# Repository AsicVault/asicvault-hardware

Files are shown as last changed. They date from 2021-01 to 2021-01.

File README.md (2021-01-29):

# Hardware design of AsicVault

https://asicvault.io/

## Schematics (Altium and PDF versions)

Schematics files of AsicVault hardware wallet rev2.0.6 are located at [**electronics**](https://github.com/AsicVault/asicvault-hardware/tree/main/electronics) folder.

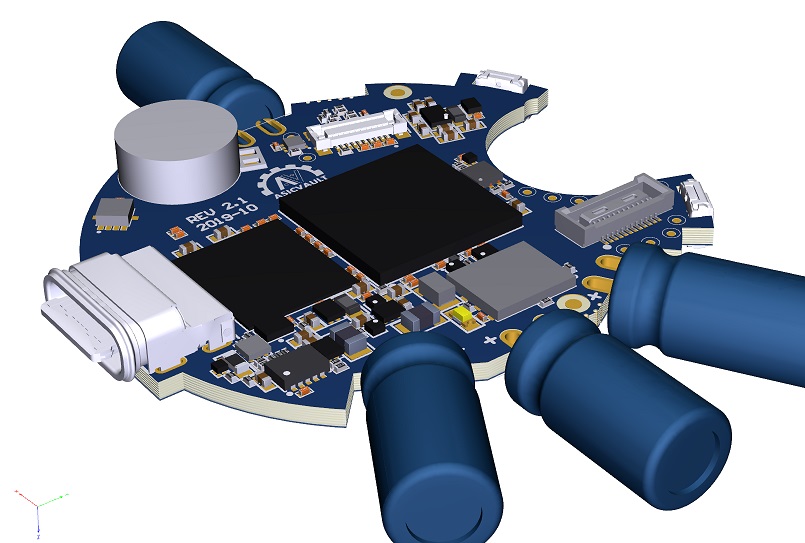
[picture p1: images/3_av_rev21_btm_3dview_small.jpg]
AsicVault PCB 3D bottom view


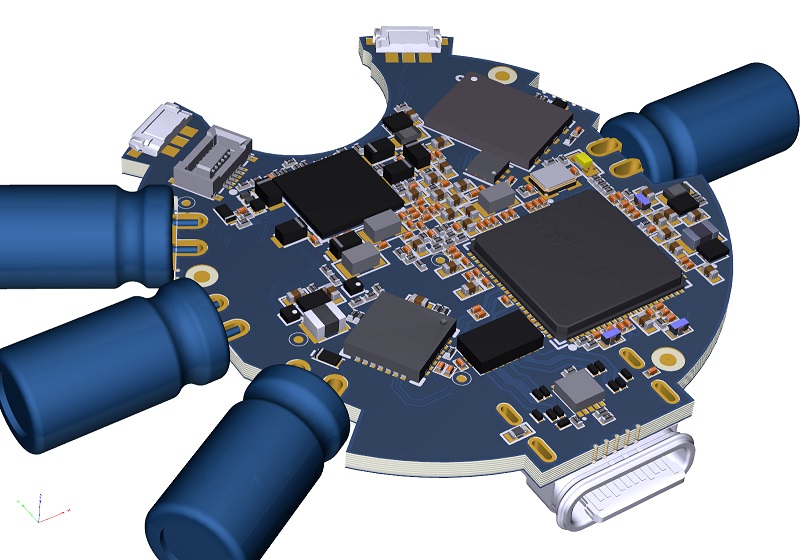
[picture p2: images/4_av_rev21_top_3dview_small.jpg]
AsicVault PCB 3D top view


## Development Kit

Development kit carrier board schematics and PCB design files are located at [**devkit**](https://github.com/AsicVault/asicvault-hardware/tree/main/devkit) folder.

## License

AsicVault Hardware is distributed under [**Solderpad Hardware License v2.1 with Commons Clause**](https://github.com/AsicVault/asicvault-hardware/blob/main/LICENSE.md) license.

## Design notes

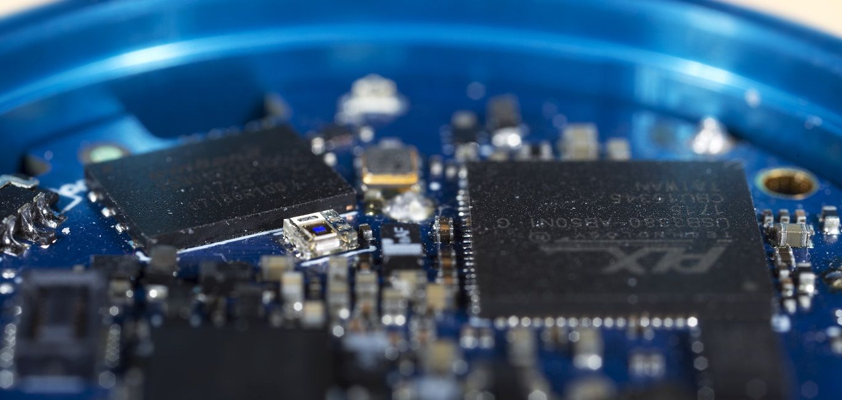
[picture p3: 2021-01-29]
photos/IMG_0519_s25.jpg

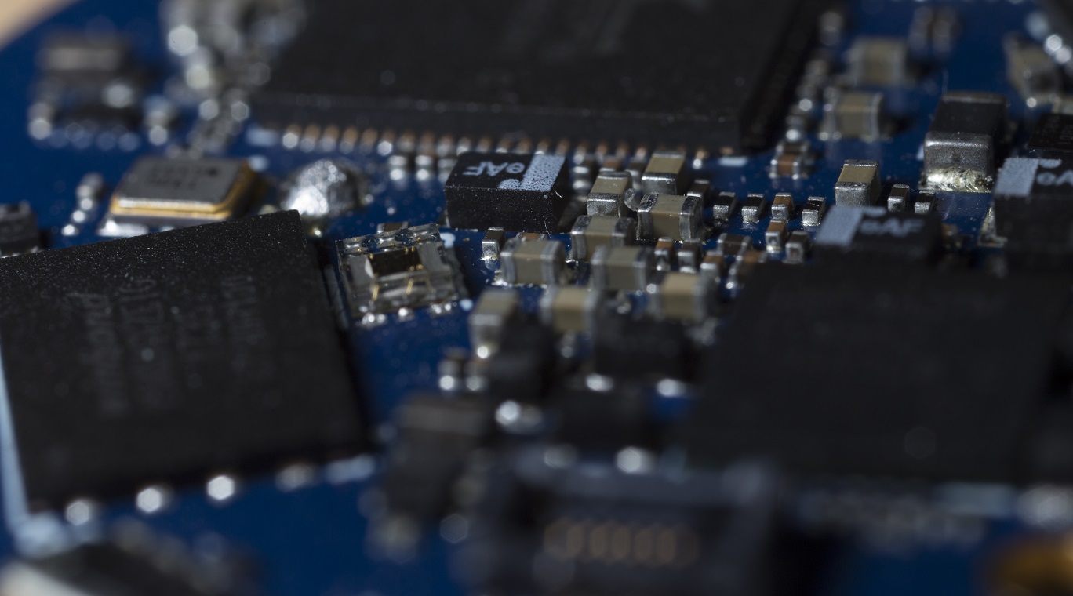
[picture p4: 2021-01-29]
photos/IMG_0346_s25.jpg

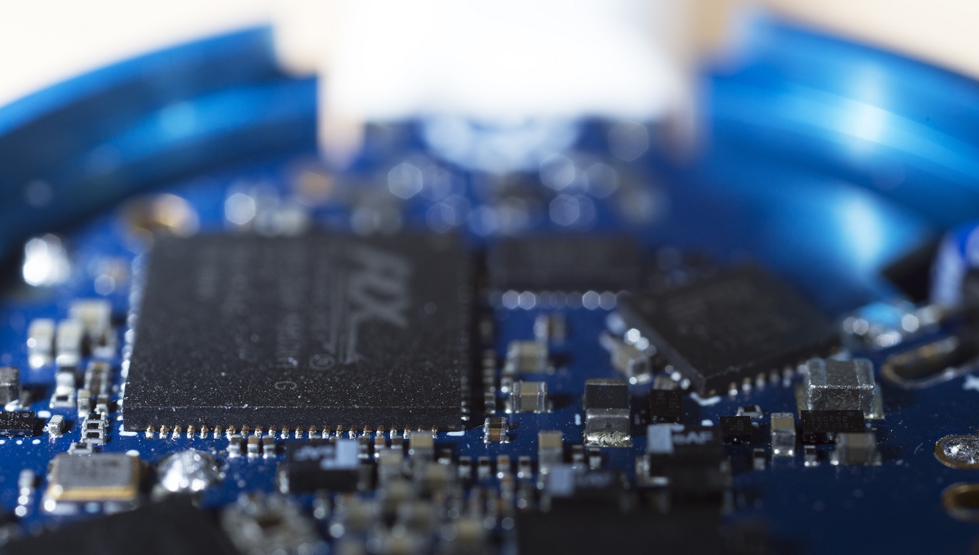
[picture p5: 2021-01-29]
photos/IMG_0522_s25.jpg

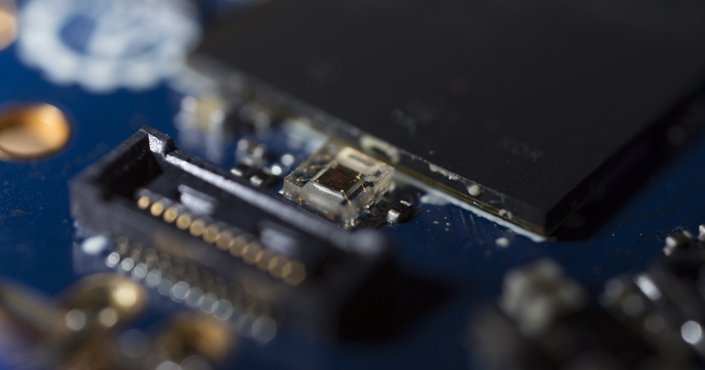
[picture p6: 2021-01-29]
photos/IMG_0318_s25.jpg

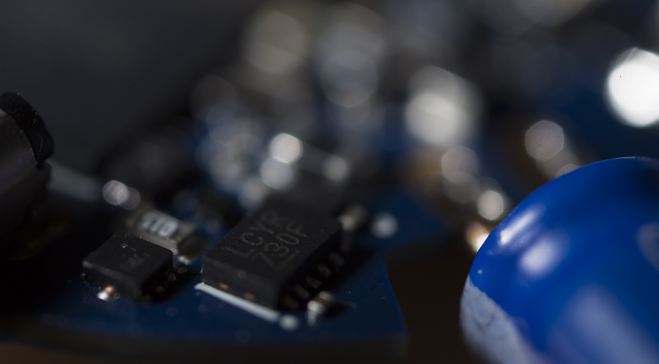
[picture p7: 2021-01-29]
photos/IMG_0329_s25.jpg

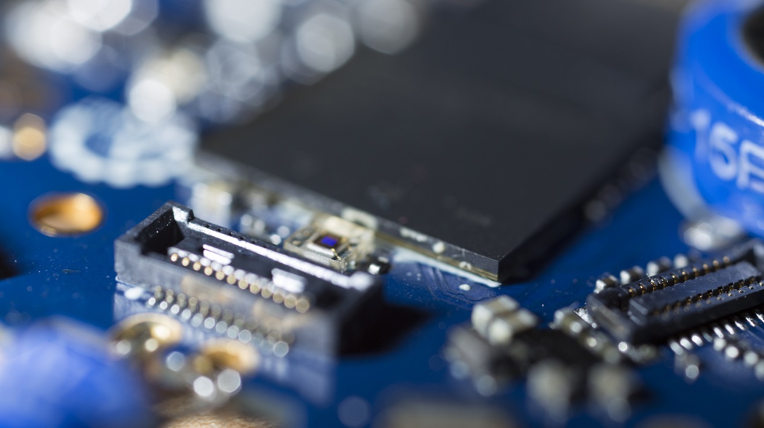
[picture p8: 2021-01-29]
photos/IMG_0317_s25.jpg

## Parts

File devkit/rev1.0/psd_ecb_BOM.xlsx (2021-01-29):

Bill of Material for | PSD_ECB
On 12/12/2017 at 14:17:52 |  |  | Tellimus | 5
Comment | Pattern | Quantity | Components |  | Tellimuse kogus | Order code | Replacement 1
0R | R0603 | 39 | R2, R3, R4, R5, R6, R7, R8, R9, R10, R11, R12, R14, R15, R16, R24, R25, R26, R27, R28, R29, R30, R31, R32, R33, R34, R35, R36, R37, R38, R40, R41, R42, R43, R44, R45, R46 |  | 195 | 603-RC0603JR-070RL (https://www.mouser.ee/ProductDetail/Yageo/RC0603JR-070RL/?qs=sGAEpiMZZMu61qfTUdNhG5eFuApKbqVdMPNPP1VDJp4%3d)
750R | R0603 | 3 | R18, R20, R22 |  | 15 | 603-RC0603FR-07750RL (https://www.mouser.ee/ProductDetail/Yageo/RC0603FR-07750RL/?qs=sGAEpiMZZMtlubZbdhIBIPrUdgJV0nB595rhZqGCp0E%3d)
1.2pF | CAPC1005X04L | 2 | C19, C20 | Capacitor, NP0, ±0.1pF | 10 | 81-GRM1555C1H1R2BA1D (https://www.mouser.ee/ProductDetail/Murata-Electronics/GRM1555C1H1R2BA01D/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)
10µH | INDC1608X06L | 1 | L2 | Inductor, 80mA, ±10% | 5 | 963-LBMF1608T100K (https://www.mouser.ee/ProductDetail/Taiyo-Yuden/LBMF1608T100K/)
100nF | 0603C | 14 | C1, C2, C3, C4, C5, C6, C9, C10, C11, C13, C14, C15, C16, C23 |  | 70 | 710-885012206071 (https://www.mouser.ee/ProductDetail/Wurth-Electronics/885012206071/)
10uF | C0805 | 2 | C8, C12 |  | 10 | 77-VJ0805G106KXQTBC (https://www.mouser.ee/ProductDetail/Vishay-Vitramon/VJ0805G106KXQTW1BC/)
15nH | INDC1005X04L | 1 | L1 | Inductor, 320mA, ±5% | 5 | 963-HK100515NJ-T (https://www.mouser.ee/ProductDetail/Taiyo-Yuden/HK100515NJ-T/)
1K | R0603 | 1 | R13 |  | 5 | 603-RC0603FR-071KL (https://www.mouser.ee/ProductDetail/Yageo/RC0603FR-071KL/)
1nF | 0603C | 1 | C7 |  | 5 | 710-885012206059 (https://www.mouser.ee/ProductDetail/Wurth-Electronics/885012206059/)
1uF | 0603C | 3 | C17, C18, C24 |  | 15 | 710-885012106010 (https://www.mouser.ee/ProductDetail/Wurth-Electronics/885012106010/)
300pF | CAPC1608X06L | 6 | C21, C25, C26, C27, C28, C29 | Capacitor, X5R, ±10% | 30 | 603-CC603JRNPO9BN301 (https://www.mouser.ee/ProductDetail/Yageo/CC0603JRNPO9BN301/?qs=sGAEpiMZZMs0AnBnWHyRQCF1lTWZ1EBLaBLolnZHR5s%3d)
32.768kHz | XTAL_3215 | 1 | X1 | EPSON TOYOCOM - FC-135 32.768KHZ ±20PPM,9.0PF - CRYSTAL, SM, WATCH | 5 | 732-FC135-32.76KAAC3 (https://www.mouser.ee/ProductDetail/Epson-Timing/FC-135-327680KA-AC3/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) | 1278037 (http://ee.farnell.com/epson/q13fc13500003-fc-135-32-768khz-9-0pf/crystal-fc-135-32-768-khz-9-pf/dp/1278037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)
4.7K | R0603 | 2 | R1, R39 |  | 10 | 603-RC0603FR-074K7L (https://www.mouser.ee/ProductDetail/Yageo/RC0603FR-074K7L/?qs=sGAEpiMZZMu61qfTUdNhG5eFuApKbqVdTnYbjySMIr8%3d)
4.7uF | 0603C | 1 | C22 |  | 5 | 581-06036D475KAT4A (https://www.mouser.ee/ProductDetail/AVX/06036D475KAT4A/)
430773034825 | 4307x30348xx_6x6x3.4 | 3 | S1, S2, S3 | WS-TASV 6x6mm J-Hook Hermetic Tact Switch, SMD version | 15 | 710-430773034825 (https://www.mouser.ee/ProductDetail/Wurth-Electronics/430773034825/)
47K | R0603 | 1 | R23 |  | 5 | 603-RC0603FR-0747KL (https://www.mouser.ee/ProductDetail/Yageo/RC0603FR-0747KL/?qs=sGAEpiMZZMu61qfTUdNhG5eFuApKbqVdtD8IoZ5tOEg%3d)
61201021621 | 61201021621 | 1 | J5 | WR-BHD 2.54mm Male Box Header | 5 | 710-61201021621 (https://www.mouser.ee/ProductDetail/Wurth-Electronics/61201021621/)
61201421621 | 61201421621 | 1 | J6 | WR-BHD 2.54mm Male Box Header | 5 | 710-61201421621 (https://www.mouser.ee/ProductDetail/Wurth-Electronics/61201421621/)
61300211121 | 61300211121 | 3 | J3, J7, J9 | WR-PHD 2.54 mm THT Pin Header, 2p | 15 | 710-61300211121 (https://www.mouser.ee/ProductDetail/Wurth-Electronics/61300211121/)
61300311121 | 61300311121 | 1 | J4 | WR-PHD 2.54 mm THT Pin Header, 3p | 5 | 710-61300311121 (https://www.mouser.ee/ProductDetail/Wurth-Electronics/61300311121/)
61300911121 | 61300911121 | 1 | J8 | WR-PHD 2.54 mm THT Pin Header, 9p | 5 | 710-61300911121 (https://www.mouser.ee/ProductDetail/Wurth-Electronics/61300911121/)
61301021121 | 61301021121 | 3 | J10, J11, J12 | WR-PHD 2.54 mm THT Dual Pin Header, 10p | 15 | 710-61301021121 (https://www.mouser.ee/ProductDetail/Wurth-Electronics/61301021121/)
62201021121 | 62201021121 | 1 | J13 | WR-PHD 1.27 mm THT Dual Pin Header, 10p | 5 | 10-62201021121 (https://www.mouser.ee/ProductDetail/Wurth-Electronics/62201021121/)
68712014022 | ZIF_0.5MM_20P | 1 | J2 |  | 5 | 710-68712014022 (https://www.mouser.ee/ProductDetail/Wurth-Electronics/68712014022/)
APTD1608LSECK/J4-PF | LED0603 | 3 | LED1, LED2, LED3 |  | 15 | 604-APTD1608LSECKJ4F (https://www.mouser.ee/ProductDetail/Kingbright/APTD1608LSECK-J4-PF/)
DF40C-24DP-0.4V(51) | DF40C-24DP-0.4V(51) | 1 | J1 |  | 5 | 798-DF40C24DP0.4V51 (https://www.mouser.ee/ProductDetail/Hirose-Electric/DF40C-24DP-04V51/)
EYSHSNZWZ | EYSHSNZWZ | 1 | U5 | EYSHSNZWZ | 5 | 963-EYSHSNZWZ (https://www.mouser.ee/ProductDetail/Taiyo-Yuden/EYSHSNZWZ/)
FPC 0.5mm RA SMD | FPC_05P-0.5mm-RA-SMD | 1 | P1 | 0.5mm FPC, 5P,Right Angle SMT,Double Contact,H=1.2mm,White, Tin plated | 5 | 538-51281-0594 (https://www.mouser.ee/ProductDetail/Molex/51281-0594/)
FT4232H Mini Module | FT2232H_MOD | 1 | U3 |  | 5 | 895-FT4232HMINIMOD (https://www.mouser.ee/ProductDetail/FTDI/FT4232H-MINI-MODULE/)
SN74CBT3257PWLE | PW016_N | 2 | U1, U2 | 4-Bit 1-of-2 FET Multiplexer/Demultiplexer | 10 | 595-SN74CBTLV3257D (https://www.mouser.ee/ProductDetail/Texas-Instruments/SN74CBTLV3257D/) | 584-ADG774BRZ-R7 (https://www.mouser.ee/ProductDetail/Analog-Devices/ADG774BRZ-REEL7/)
TLV74328PDBVR | SOT23-5 | 1 | U4 |  | 5 | 595-TLV74328PDBVR (https://www.mouser.ee/ProductDetail/Texas-Instruments/TLV74328PDBVR/)
Muu kaup
20pin FPC cable |  | 1 |  |  | 5 | 710-687720200002 (https://www.mouser.ee/Search/ProductDetail.aspx?qs=P%2fTEqz%252bQfneX3xTMEstNag%3d%3d)
MSP-FET |  | 1 | MCU programmer |  | 1 | 595-MSP-FET (https://www.mouser.ee/ProductDetail/Texas-Instruments/MSP-FET/)
NRF52-DK |  | 1 | Bluetooth/802.15.1 Development Tools NRF52 Dev Kit for nRF52832 SoC |  | 1 | 949-NRF52-DK (https://www.mouser.ee/ProductDetail/Nordic-Semiconductor/NRF52-DK/?qs=79dOc3%2f91%2fccrafuGv4fOw%3d%3d)
2.54mm jumper |  | 10 |  |  | 50 | 710-60900213421 (https://www.mouser.ee/ProductDetail/Wurth-Electronics/60900213421/) | 535-ME-100 (https://www.mouser.ee/ProductDetail/Aries-Electronics/ME-100/)
vibration motor | 307-105 | 1 | 7MM VIBRATION MOTOR - 2MM TYPE |  | 5 | 307-105 (https://www.precisionmicrodrives.com/product/307-105-7mm-vibration-motor-2mm-type)

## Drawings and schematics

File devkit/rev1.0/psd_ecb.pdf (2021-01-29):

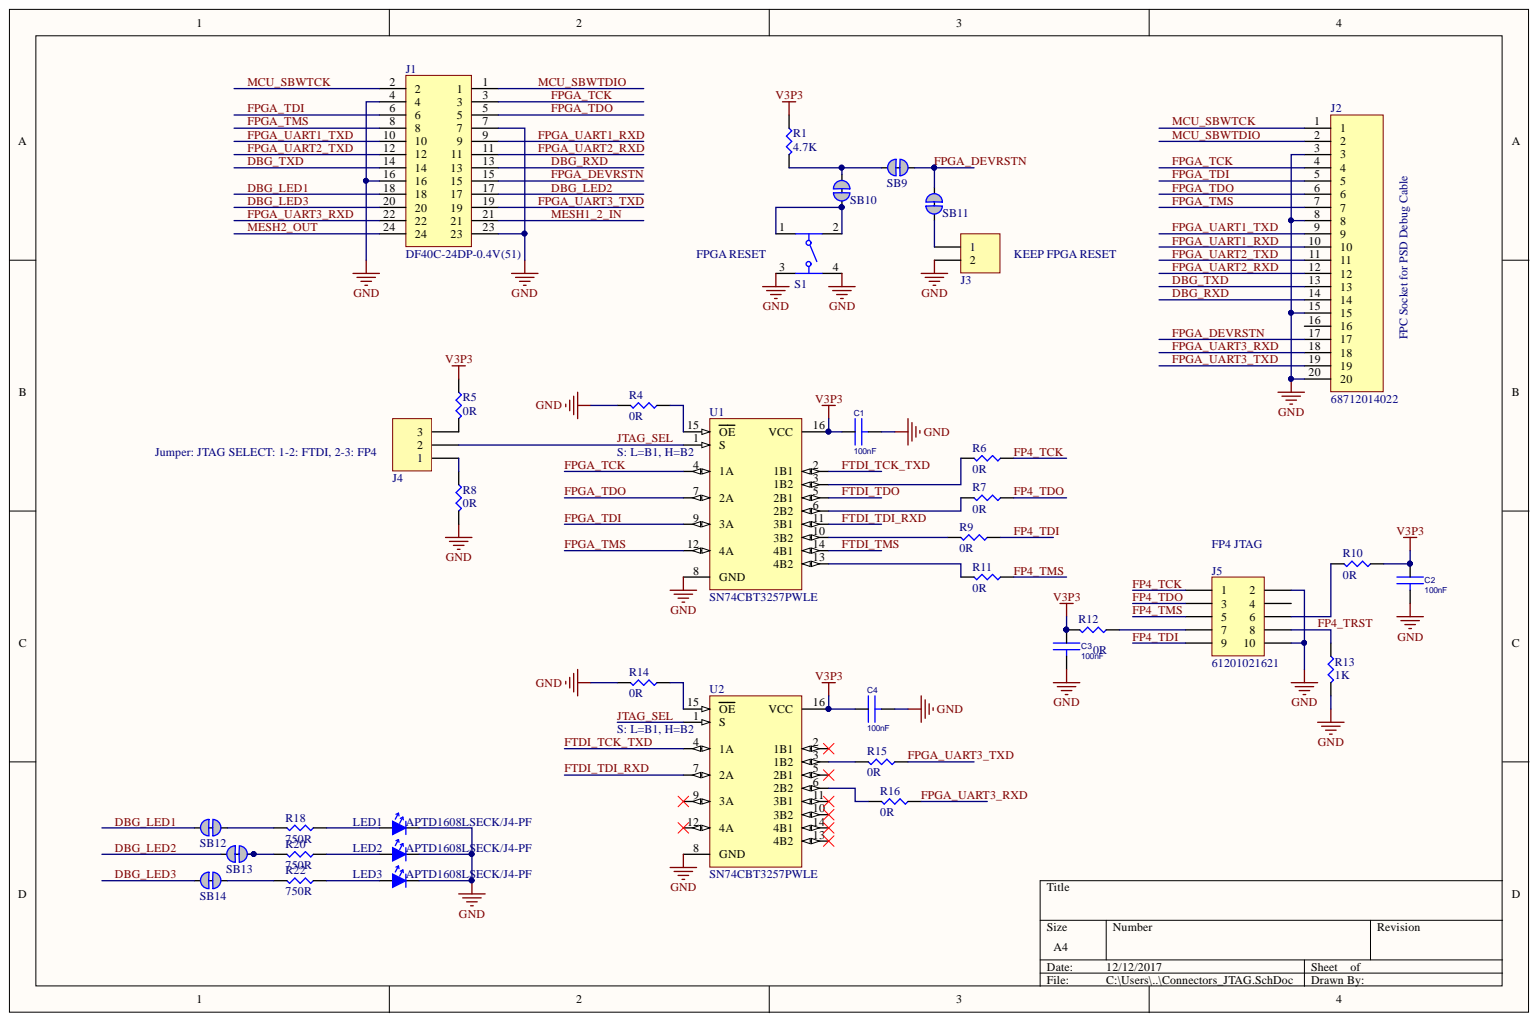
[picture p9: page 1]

FPC Socket for PSD Debug Cable

Jumper: JTAG SELECT: 1-2: FTDI, 2-3: FP4

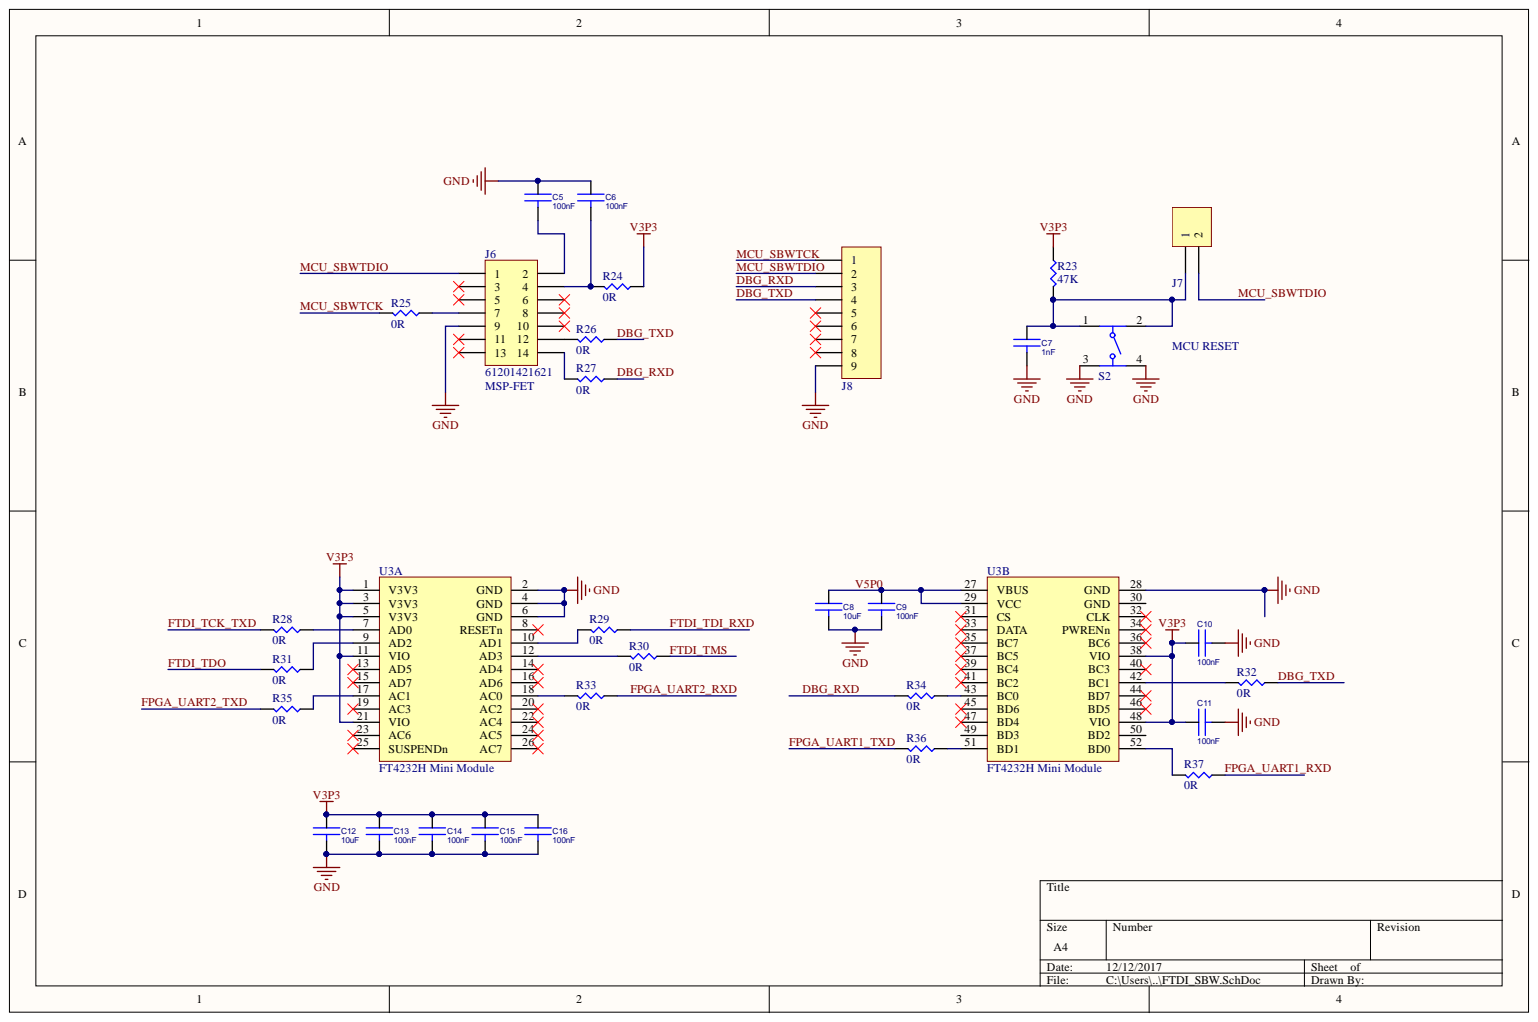
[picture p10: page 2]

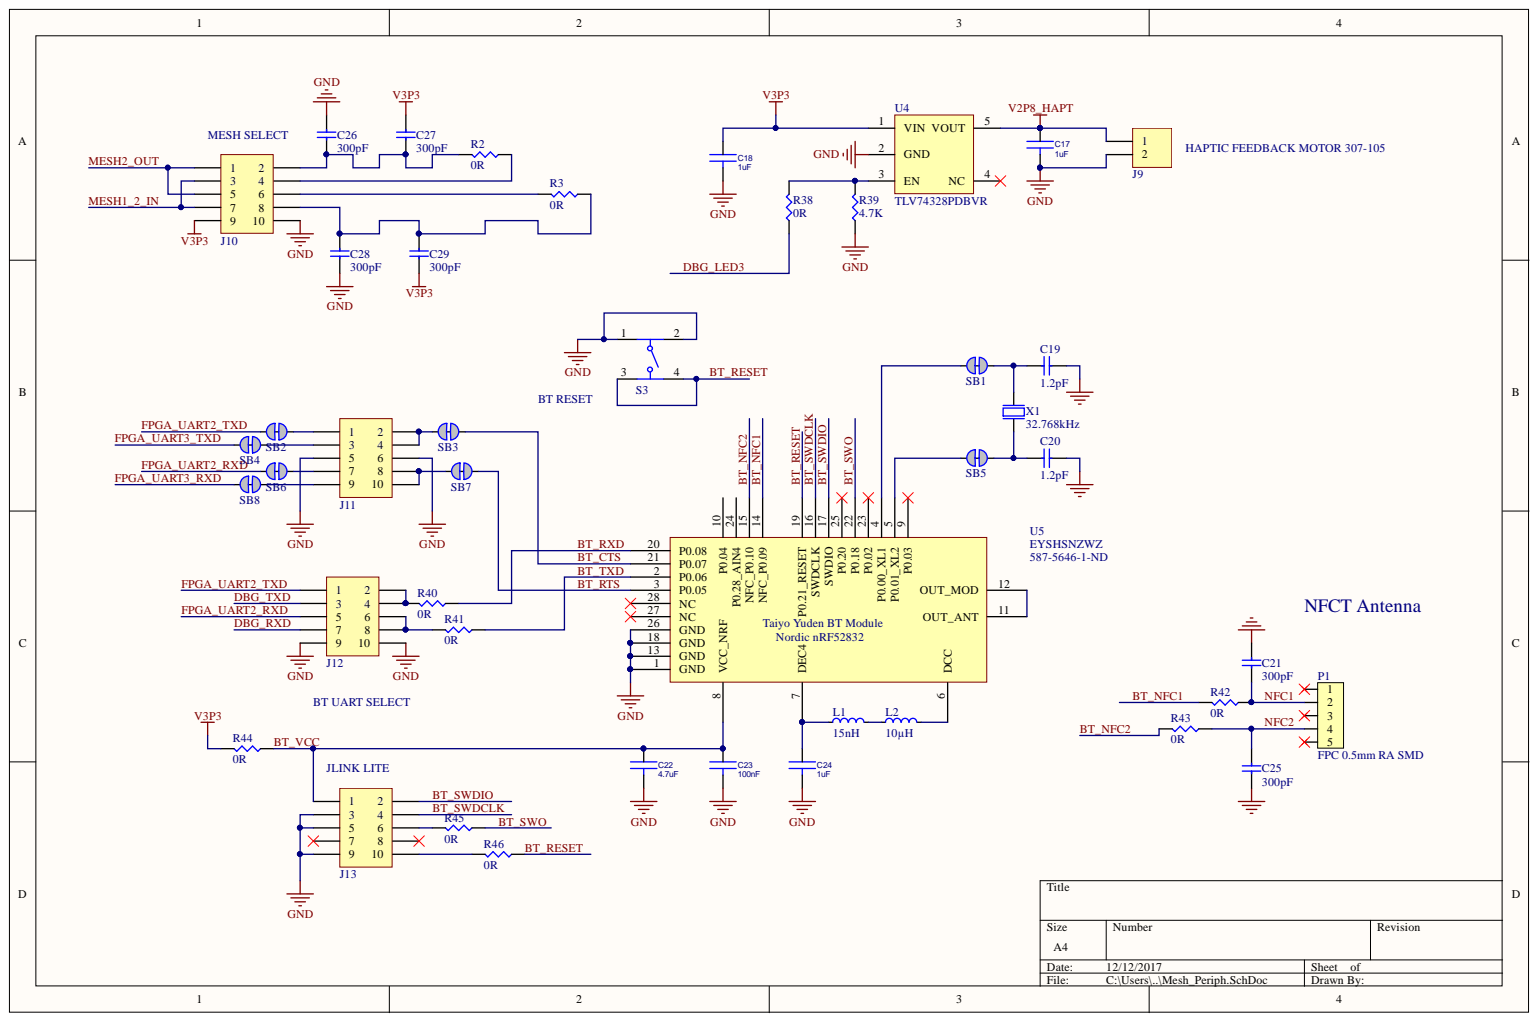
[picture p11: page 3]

BT_CTS | P0.07 21
BT_TXD | P0.06 2

Taiyo Yuden BT Module
Nordic nRF52832

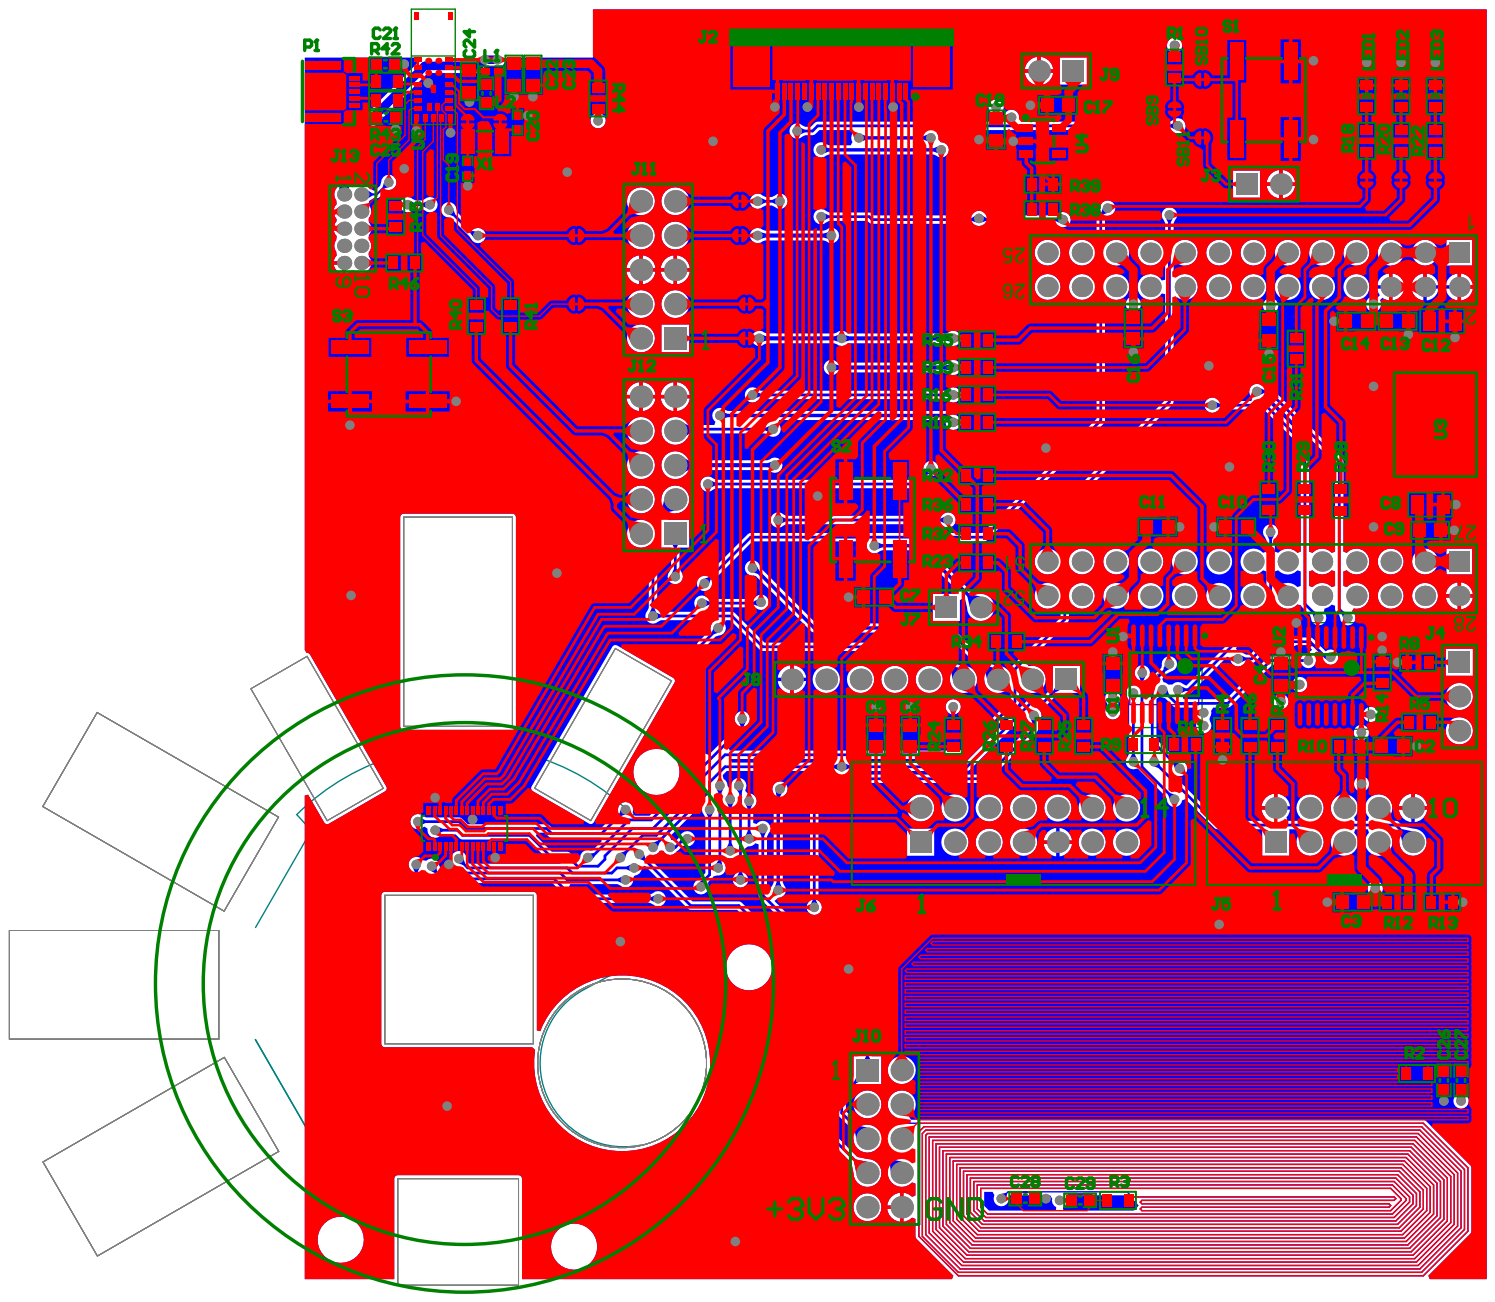
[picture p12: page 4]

Bill of Materials | <Parameter Title not found>
Source Data From: | psd_ecb.PrjPcb
Project: | | psd_ecb.PrjPcb
Variant: | | None
Creation Date: 12/12/2017 | 18:17:56
Print Date: | 12-Dec-17 | 6:18:03 PM
Footprint | Comment | LibRef | Designator | Description | Quantity
| | | C13, C14, C15, C16, C23 | | 14
0603C | 100nF | 100nF/0603 | C1, C2, C3, C4, C5, C6, C9, C10, C11,
0603C | 1nF | 100nF/0603 | C7 | | 1
C0805 | 10uF | 10uF/0805/16V | C8, C12 | | 2
0603C | 1uF | 1uF/0603/16V | C17, C18, C24 | | 3
CAPC1005X0 4L | 1.2pF | CAP_0402 | C19, C20 | Capacitor, NP0, ±0.1pF | 2
CAPC1608X0 6L | 300pF | CAP_0603 | C21, C25, C26, C27, C28, C29 | Capacitor, X5R, ±10% | 6
0603C | 4.7uF | 1uF/0603/16V | C22 | | 1
DF40C-24DP- 0.4V(51) | DF40C-24DP-
| 0.4V(51) | DF40C-24DP-
| | 0.4V(51) | J1 | | 1
ZIF_0.5MM_2 0P | 68712014022 | 68712014022 | J2 | | 1
61300211121 | 61300211121 | 61300211121 | J3, J7, J9 | WR-PHD 2.54 mm THT Pin Header, 2p | 3
61300311121 | 61300311121 | 61300311121 | J4 | WR-PHD 2.54 mm THT Pin Header, 3p | 1
61201021621 | 61201021621 | 61201021621 | J5 | WR-BHD 2.54mm Male Box Header | 1
61201421621 | 61201421621 | 61201421621 | J6 | WR-BHD 2.54mm Male Box Header | 1
61300911121 | 61300911121 | 61300911121 | J8 | WR-PHD 2.54 mm THT Pin Header, 9p | 1
61301021121 | 61301021121 | 61301021121 | J10, J11, J12 | WR-PHD 2.54 mm THT Dual Pin Header,
| | | | 10p | 3
62201021121 | 62201021121 | 62201021121 | J13 | WR-PHD 1.27 mm THT Dual Pin Header,
| | | | 10p | 1
INDC1005X04 L | 15nH | L0402-15n | L1 | Inductor, 320mA, ±5% | 1
INDC1608X06 L | 10µH | L0603-10µ | L2 | Inductor, 80mA, ±10% | 1
LED0603 | APTD1608LSEC
| K/J4-PF | LED_ORGN_06
| | 03_KB | LED1, LED2, LED3 | | 3
FPC_05P- 0.5mm-RA- SMD | FPC 0.5mm RA
| SMD | FPC_05P-
| | 0.5mm | P1 | 0.5mm FPC, 5P,Right Angle SMT,Double
| | | | Contact,H=1.2mm,White, Tin plated | 1
R0603 | 4.7K | 1K/1%/0603 | R1, R39 | 2
R0603 | 0R | 1K/1%/0603 | R2, R3, R4, R5, R6, R7, R8, R9, R10,
| | | R11, R12, R14, R15, R16, R24, R25, R26,
| | | R27, R28, R29, R30, R31, R32, R33, R34,
| | | R35, R36, R37, R38, R40, R41, R42, R43,
| | | R44, R45, R46 | 36
R0603 | 1K | 1K/1%/0603 | R13 | 1
R0603 | 750R | 1K/1%/0603 | R18, R20, R22 | 3
R0603 | 47K | 1K/1%/0603 | R23 | 1
4307x30348x
x_6x6x3.4
430773034825 | 430773034825 | S1, S2, S3 | WS-TASV 6x6mm J-Hook Hermetic Tact
Switch, SMD version

3

PW016_N SN74CBT3257P
WLE

SN74CBT3257P
WLE
U1, U2 | 4-Bit 1-of-2 FET Multiplexer/Demultiplexer | 2

FT2232H_M
OD

FT4232H Mini
Module
FT2232H_MOD | U3 | 1
SOT23-5 | TLV74328PDBV
R
RT9198-28PBR | U4 | 1

EYSHSNZW
Z
EYSHSNZWZ | EYSHSNZWZ | U5 | EYSHSNZWZ | 1
XTAL_3215 | 32.768kHz | XTAL_FC-135
32.768k
X1 | EPSON TOYOCOM - FC-135 32.768KHZ
±20PPM,9.0PF - CRYSTAL, SM, WATCH

1

100
Approved | Notes

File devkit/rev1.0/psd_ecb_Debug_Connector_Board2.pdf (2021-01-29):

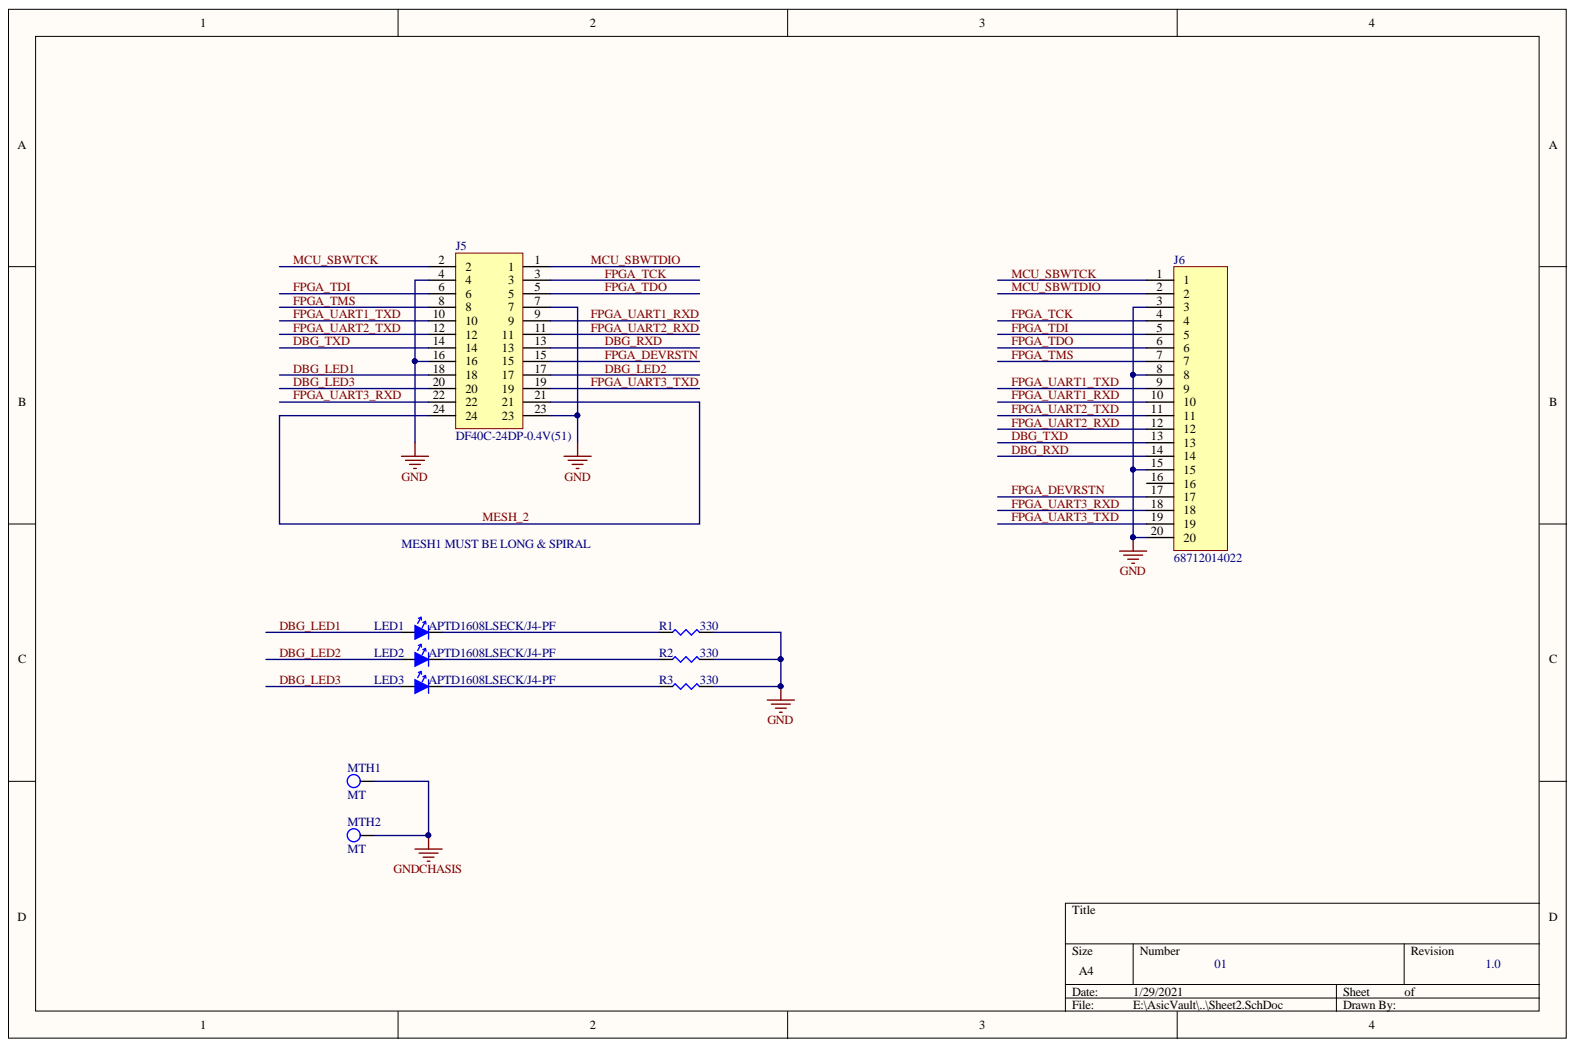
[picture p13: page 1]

MESH1 MUST BE LONG & SPIRAL

Size A4 | Number 01 | Revision 1.0

Date: 1/29/2021 | Sheet of
File: E:\AsicVault\..\Sheet2.SchDoc | Drawn By:

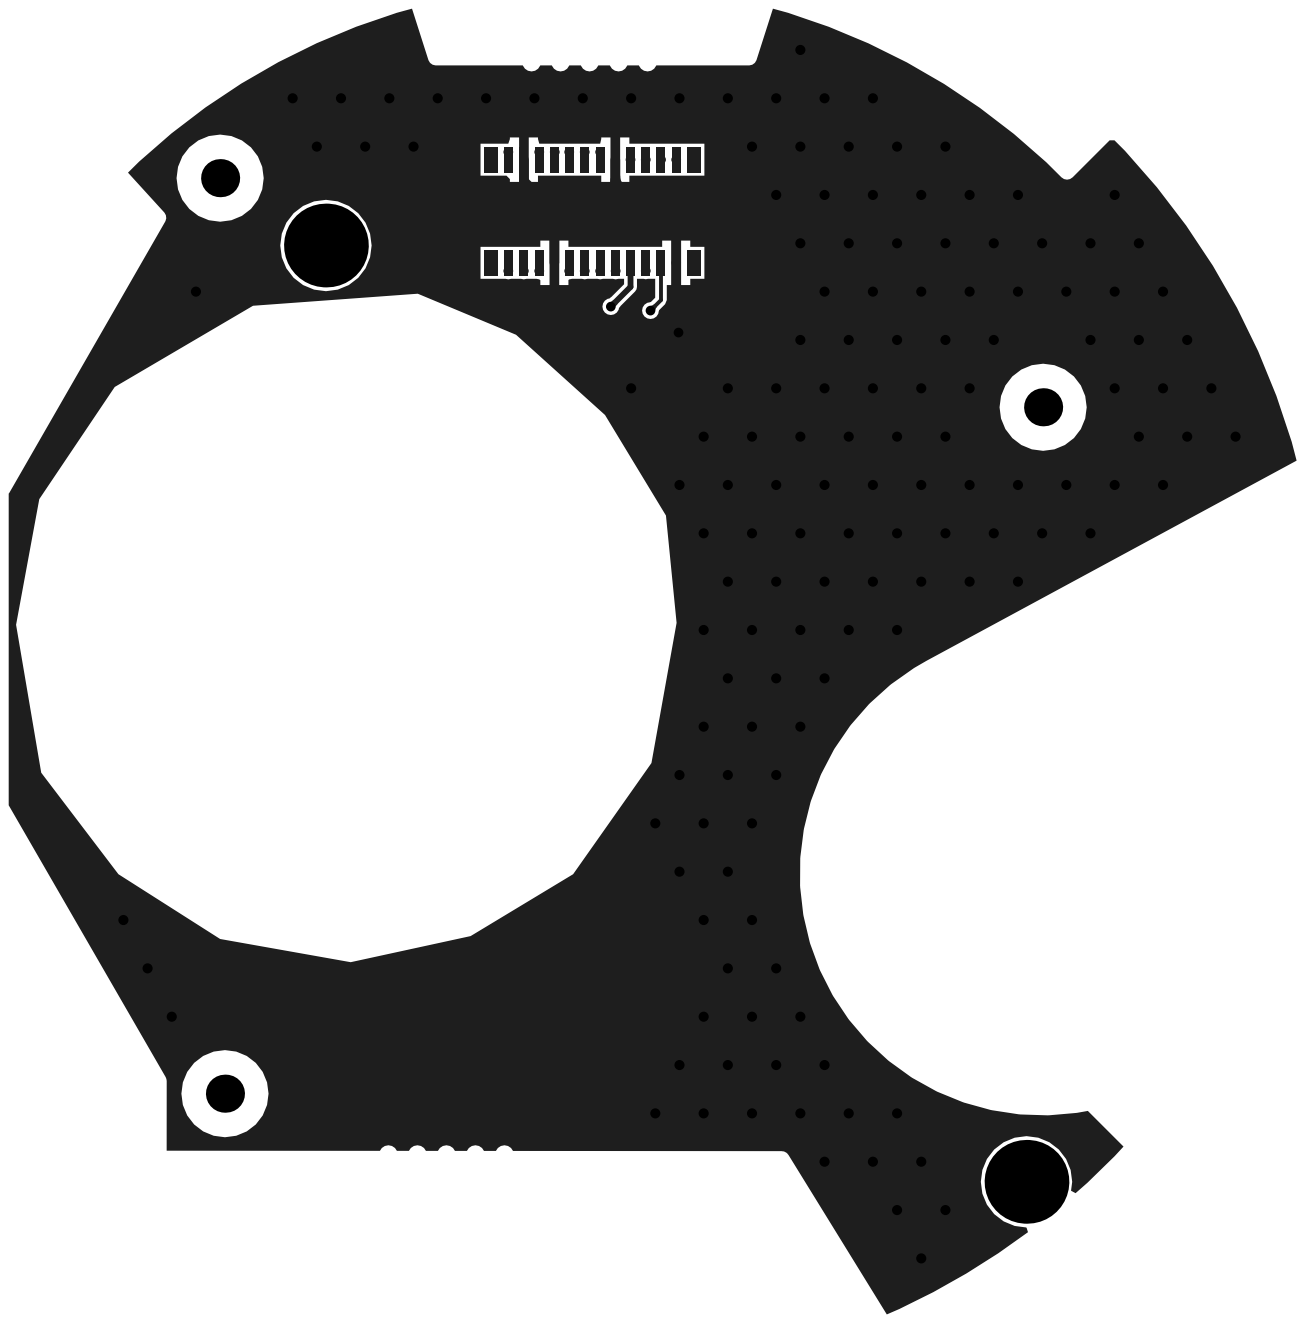
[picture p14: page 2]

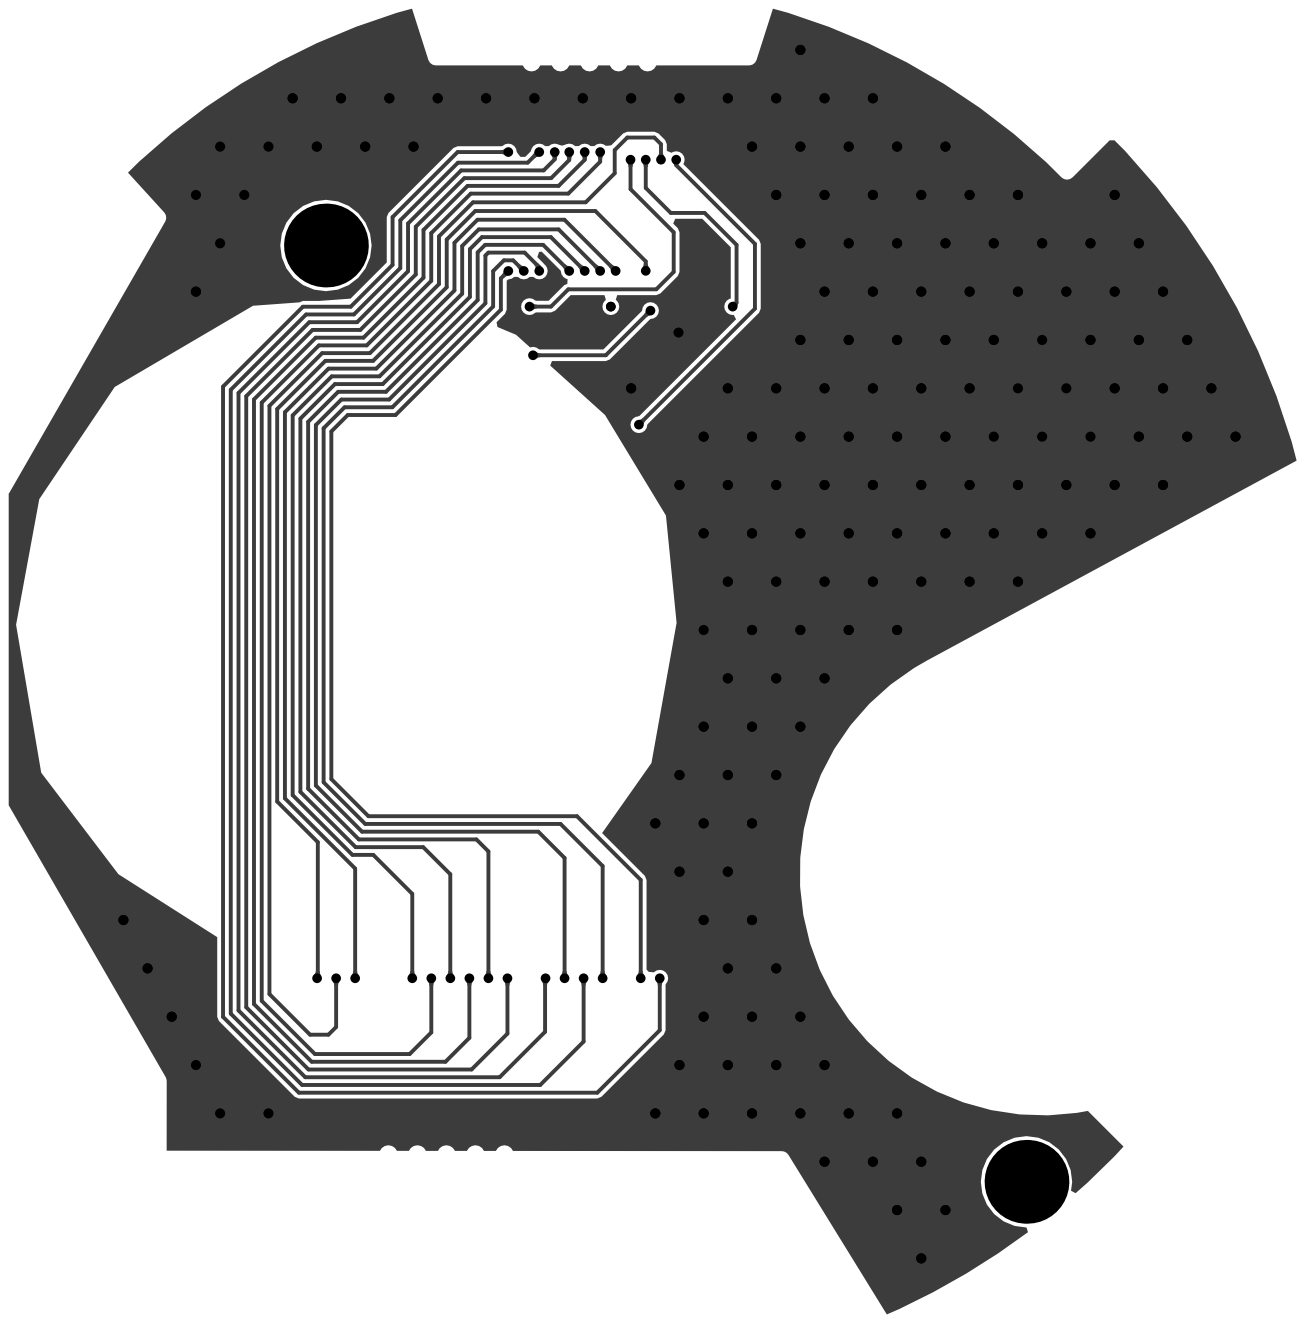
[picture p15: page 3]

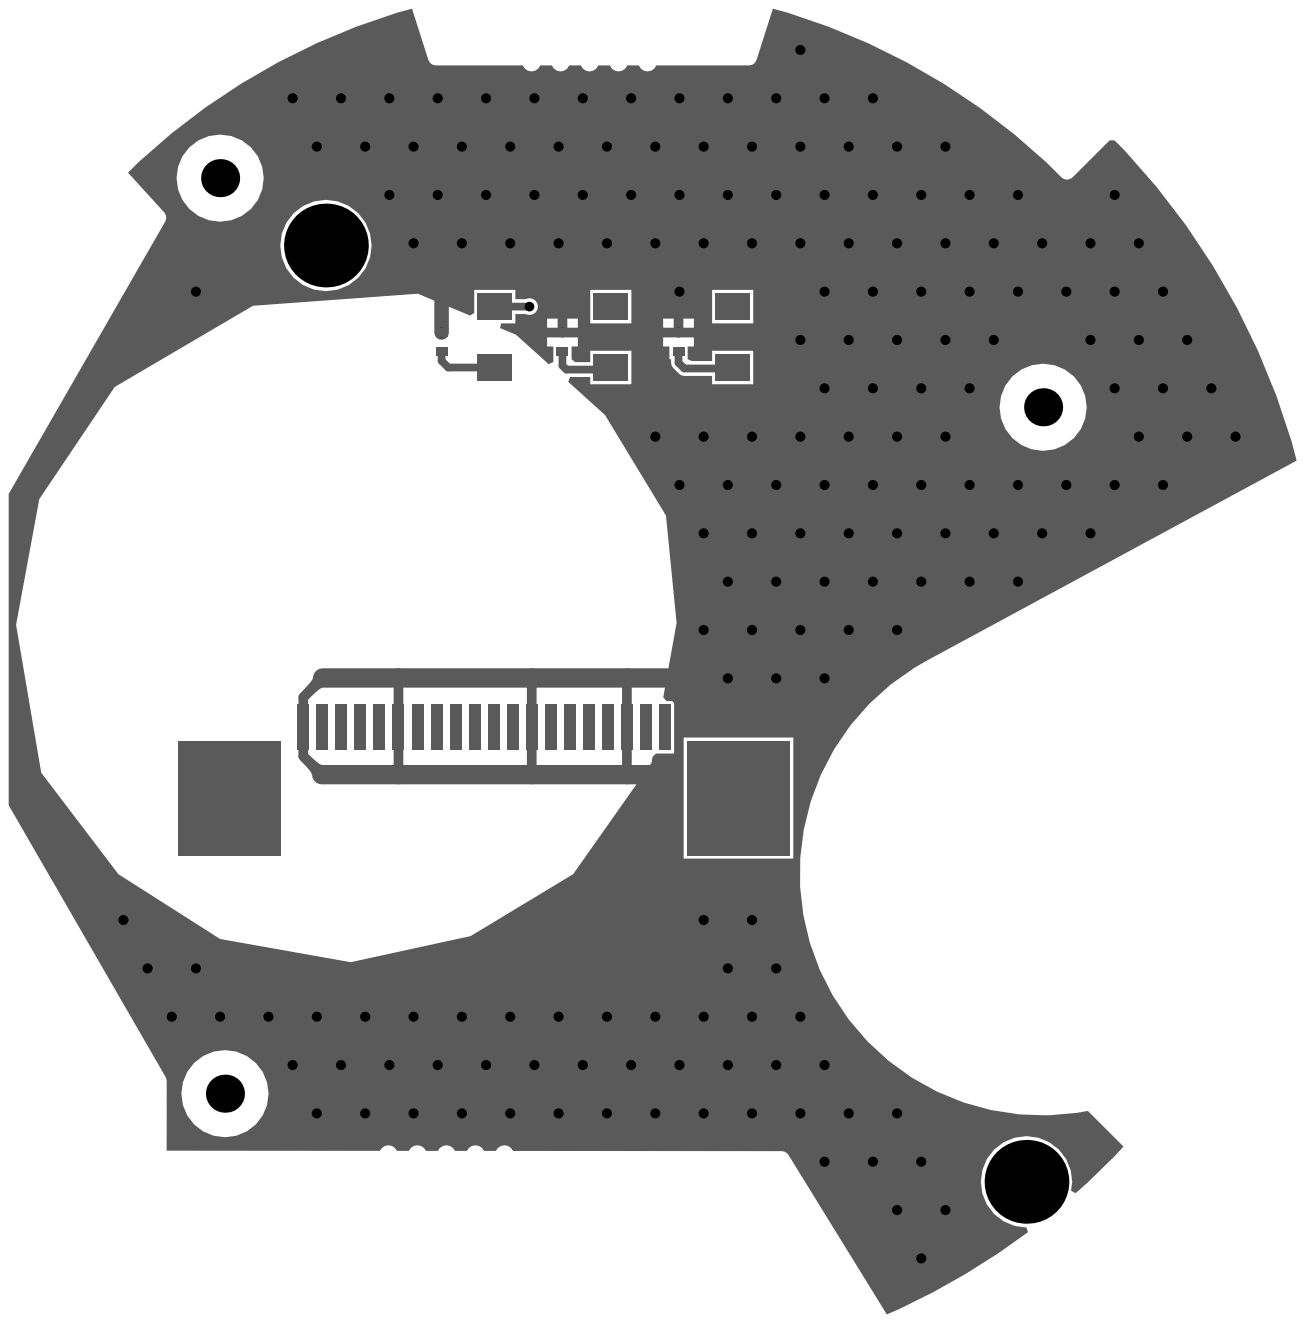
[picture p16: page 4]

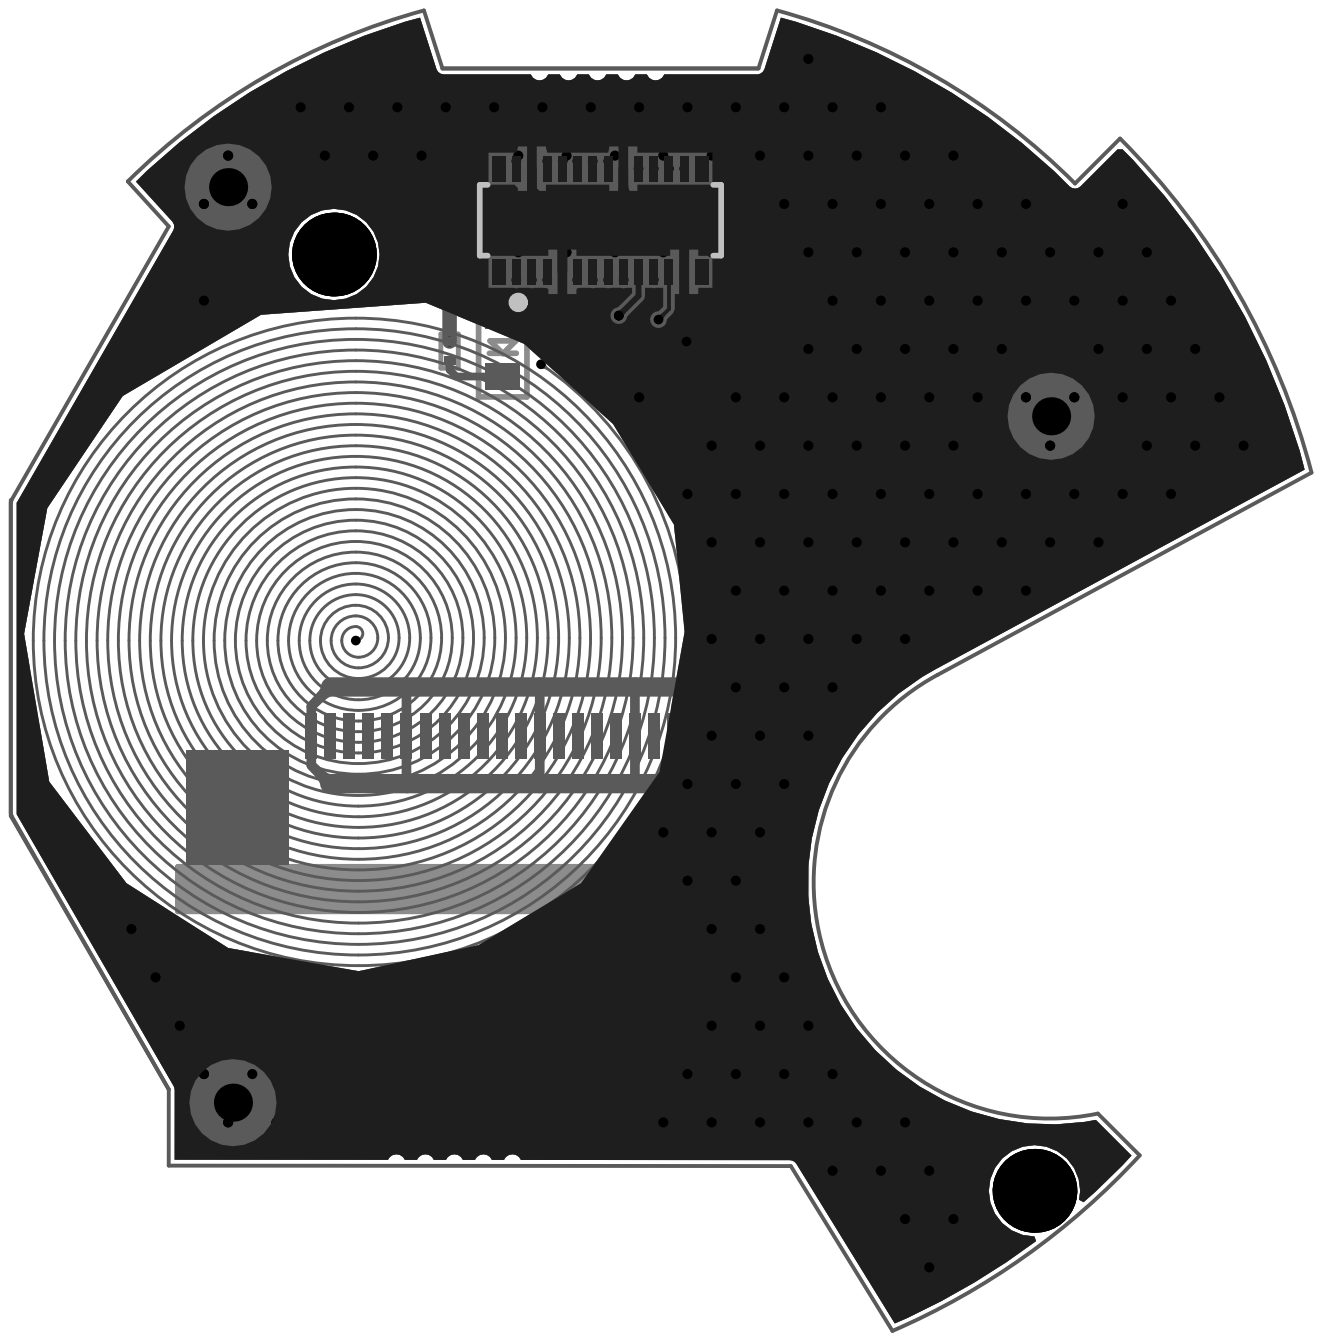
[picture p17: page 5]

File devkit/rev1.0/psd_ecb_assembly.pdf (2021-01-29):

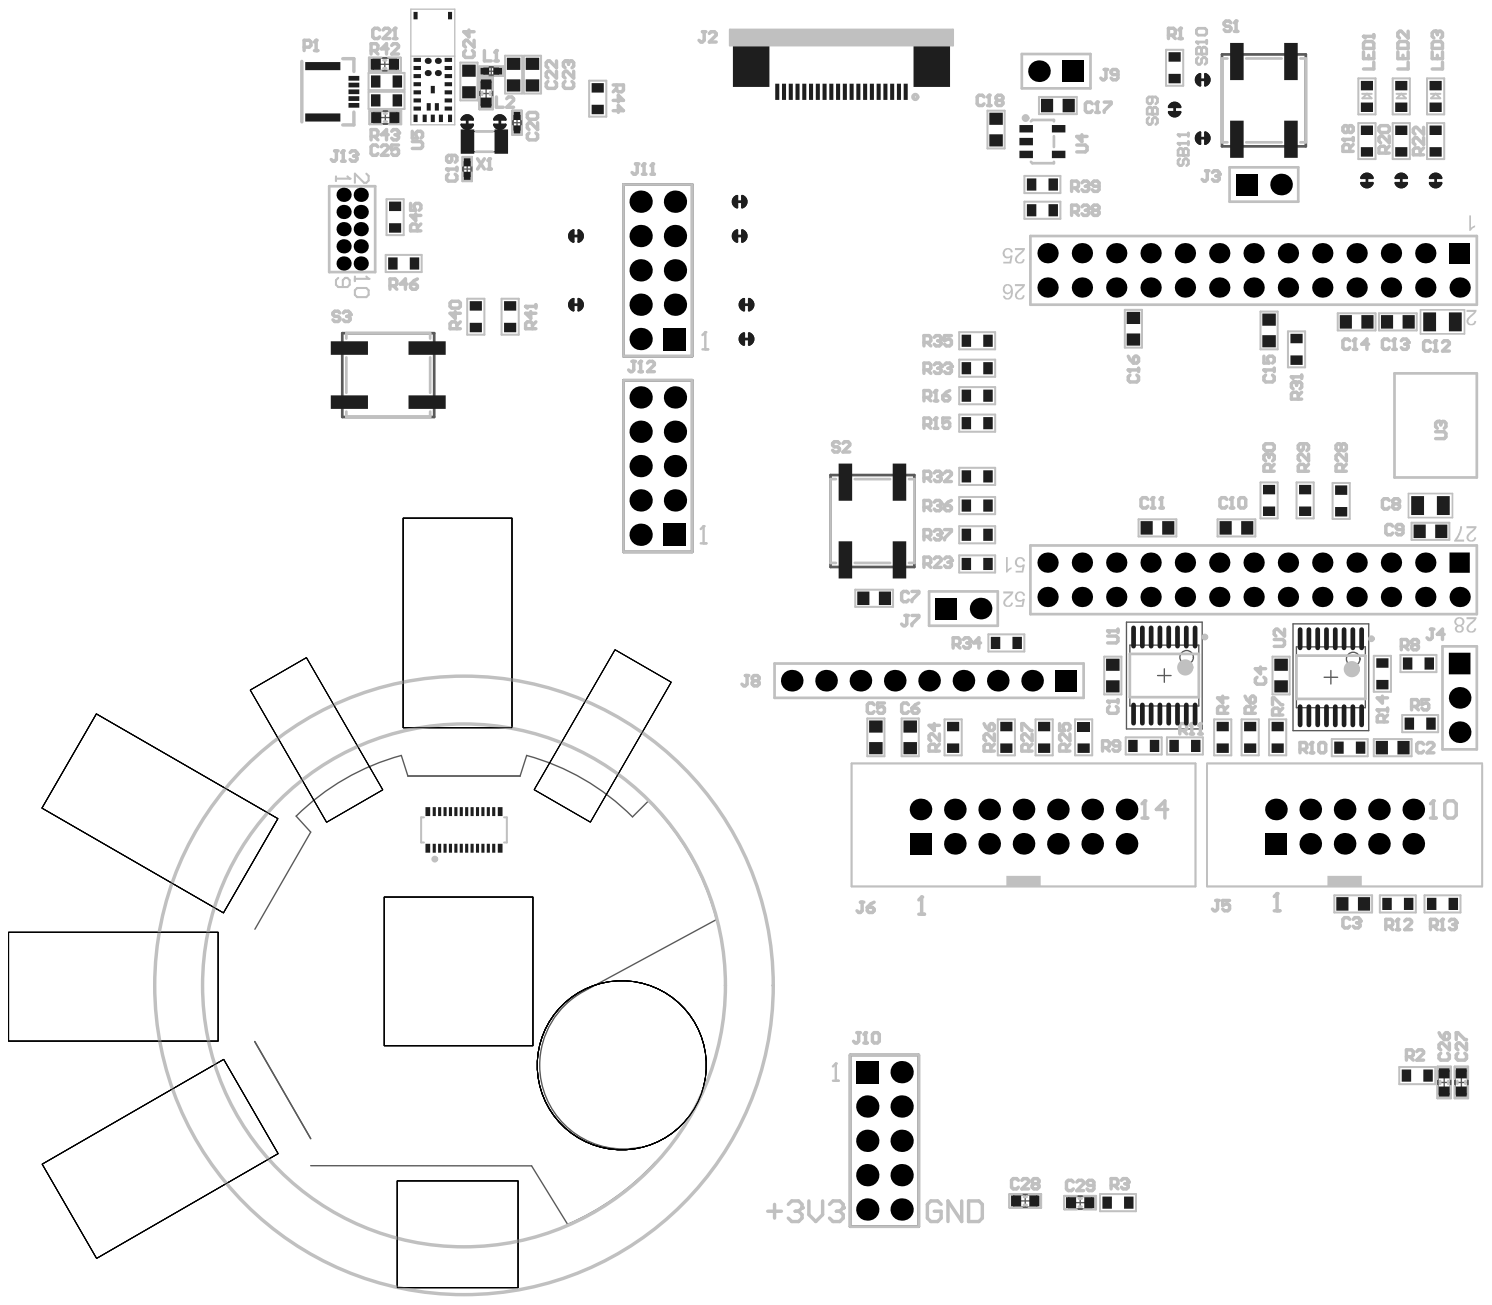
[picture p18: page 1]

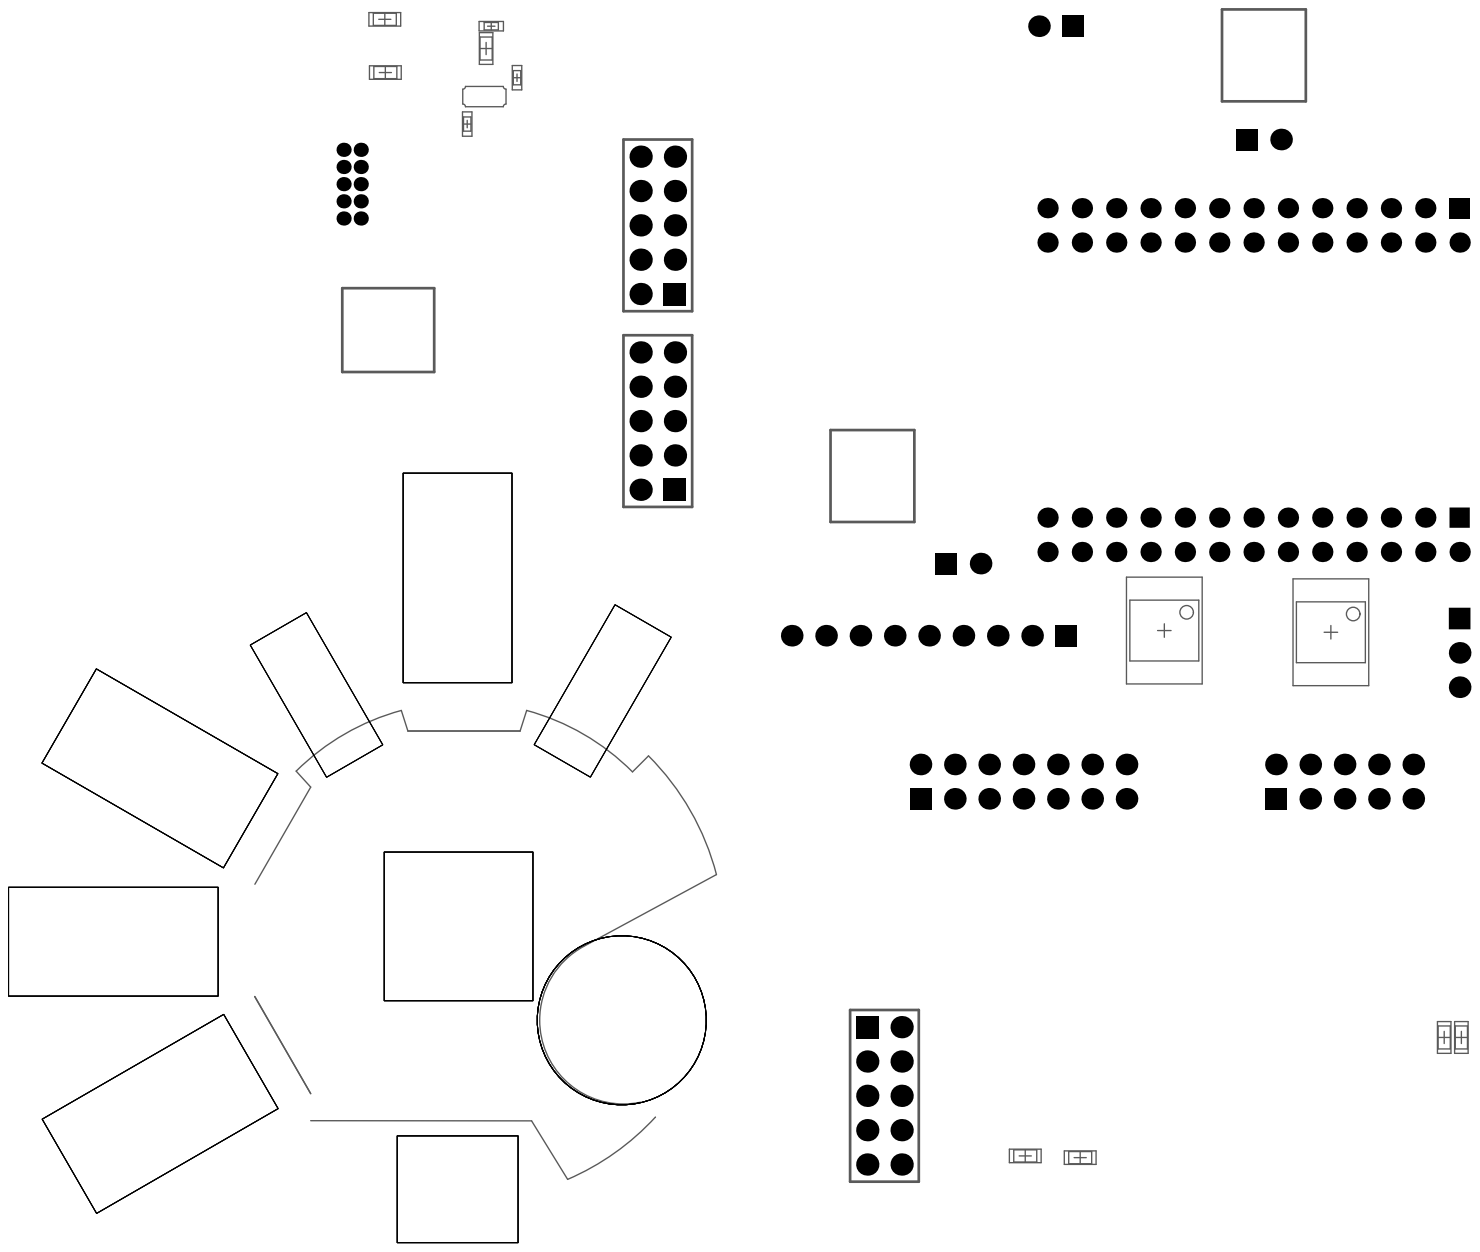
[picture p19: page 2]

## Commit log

2021-01-28 add schematics
    [01-LPDDR_FLASH.SchDoc, 02-FPGA_IO_MIPI_TS.SchDoc, 03-FPGA_DECOUPLING.SchDoc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]
2021-01-28 PCB 3D pictures
2021-01-28 PCB small pictures
2021-01-29 PCB photos
2021-01-29 Schematics link
2021-01-29 Development Kit
    [psd_ecb_BOM.xlsx, psd_ecb_BOM_assembly.xlsx]
2021-01-29 Debug connector
